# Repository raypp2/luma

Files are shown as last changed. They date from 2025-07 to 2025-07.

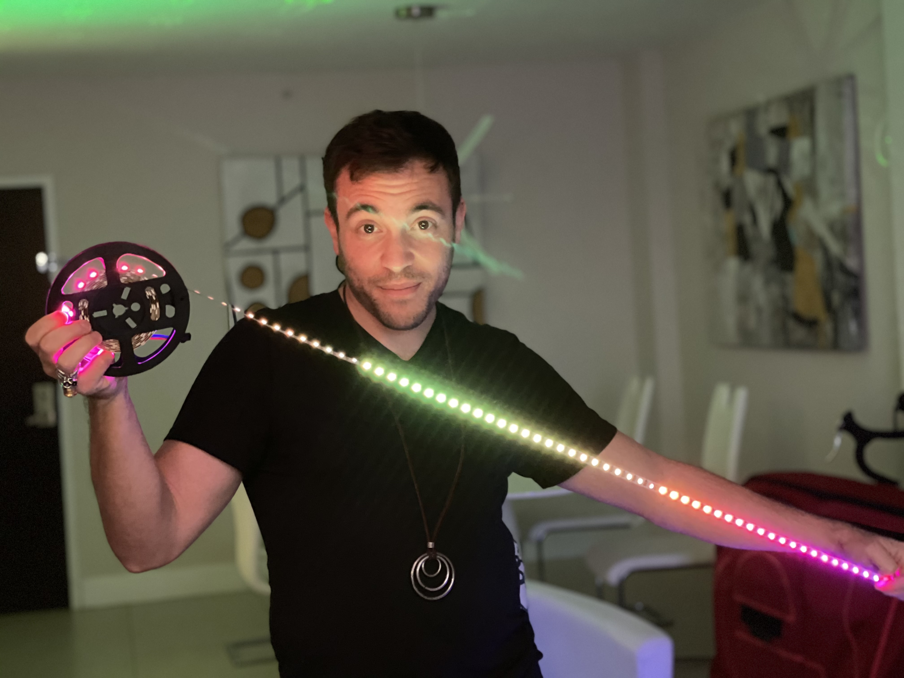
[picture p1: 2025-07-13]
microsite/teamPhotos/ray.jpg

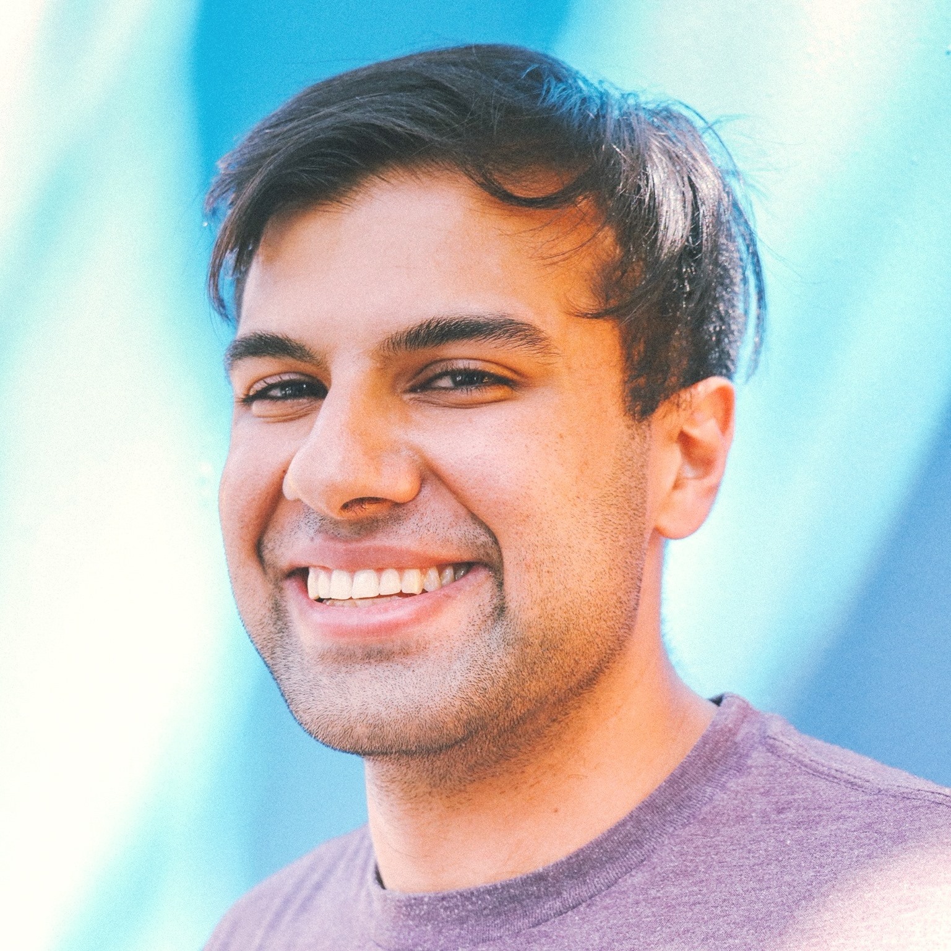
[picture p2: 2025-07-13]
microsite/teamPhotos/neil.jpg

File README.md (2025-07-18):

# Luma LED Pendant

<u>Overview</u> &nbsp;&nbsp;&nbsp;|&nbsp;&nbsp;&nbsp; [🧭 Laser Cutting](./documentation/laser.md) &nbsp;&nbsp;&nbsp;|&nbsp;&nbsp;&nbsp; [🛠️ 3D Printing](./documentation/3dmodel.md) &nbsp;&nbsp;&nbsp;|&nbsp;&nbsp;&nbsp; [🔮 Roadmap](./documentation/roadmap.md)

*This is a short description*

**Technical Notes**:
- Bullet 1
- Bullet 2

## 🙋‍♂️ Who is this for

Something about who this is for, what it does, and why it is useful.

## TODO

[] Apply google analytics
[] Write basic documentation on Github
[] Update team to instagram tags

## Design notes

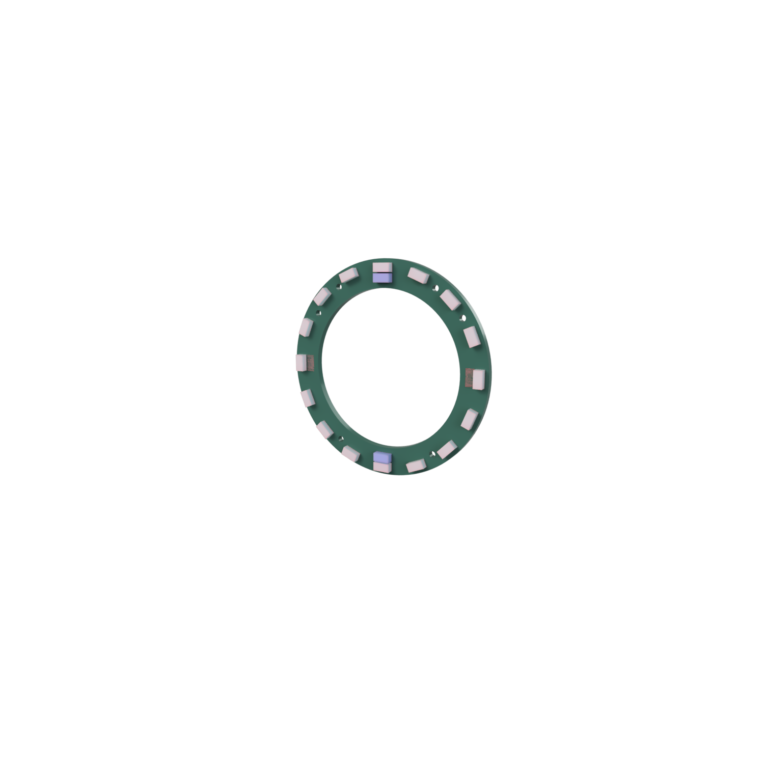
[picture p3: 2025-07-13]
moodBoardAssets/pcb.png

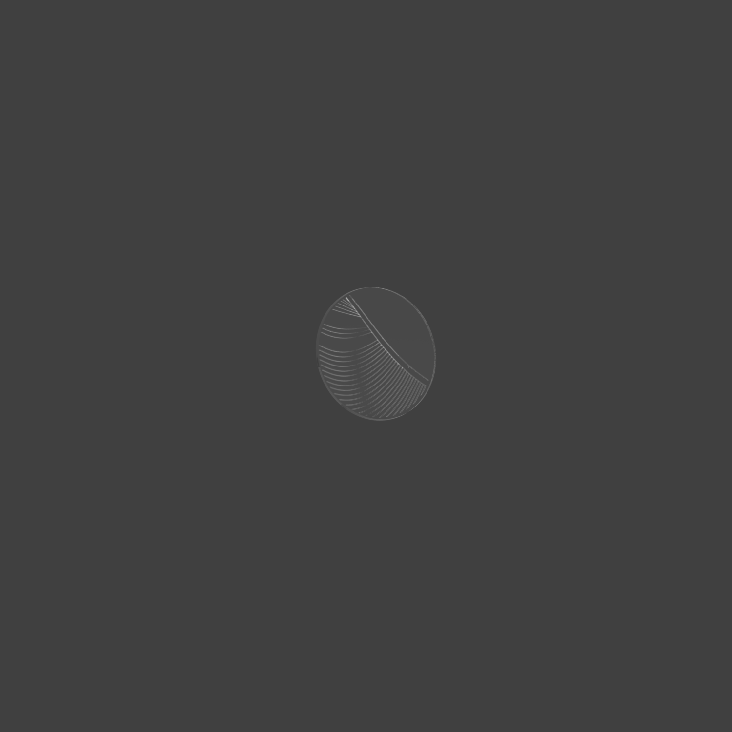
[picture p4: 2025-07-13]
moodBoardAssets/acrylic-back.png

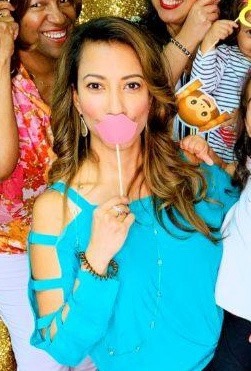
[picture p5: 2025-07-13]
microsite/teamPhotos/trisha.jpg

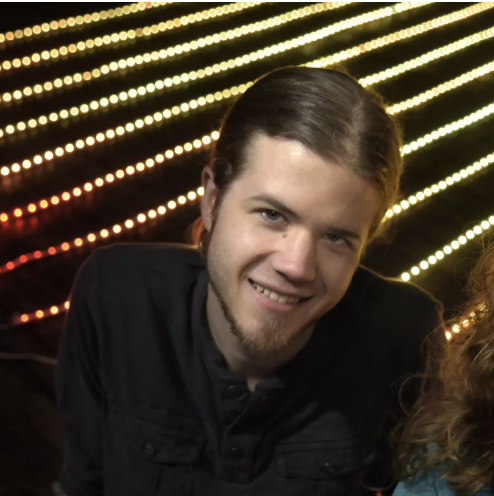
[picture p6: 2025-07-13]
microsite/teamPhotos/kyle.png

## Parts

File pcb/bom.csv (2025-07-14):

Comment | Designator | Footprint | LCSC Part Number
0.1uF | C1,C2,C3,C4,C5,C6,C7,C8,C9,C10,C11,C12,C13,C14,C15,C16,C17 | 0402 | C1525
SK6812SIDE-A-S Side edmit addressible LED | LED18,LED11,LED17,LED3,LED10,LED9,LED13,LED8,LED6,LED16,LED2,LED12,LED7,LED5,LED14,LED4,LED1,LED15,LED19,LED20 | SMD-4P,4x1.6mm | C5378737
TS-1187A-C-J-B 5.1mm momentary button 5mm plunger | SW1,SW2 | SMD | C318885
ATtiny1616-M | U1 | QFN-20-EP | C507118

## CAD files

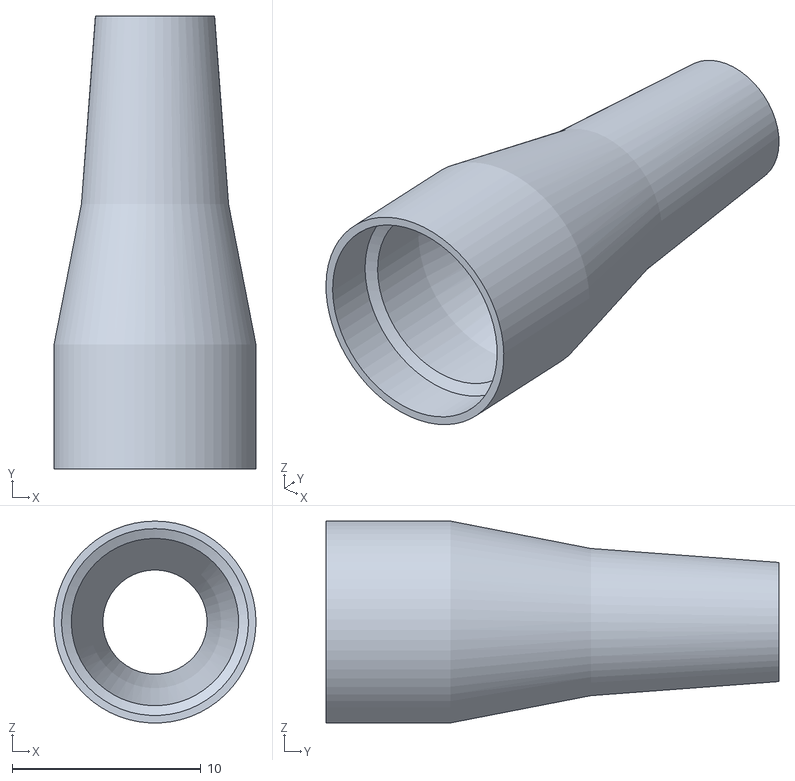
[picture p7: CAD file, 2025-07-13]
batteryEnclosure3D/Luma Pendant 3 Battery v7 wire sleeve.stl
10.7 x 24.0 x 10.7

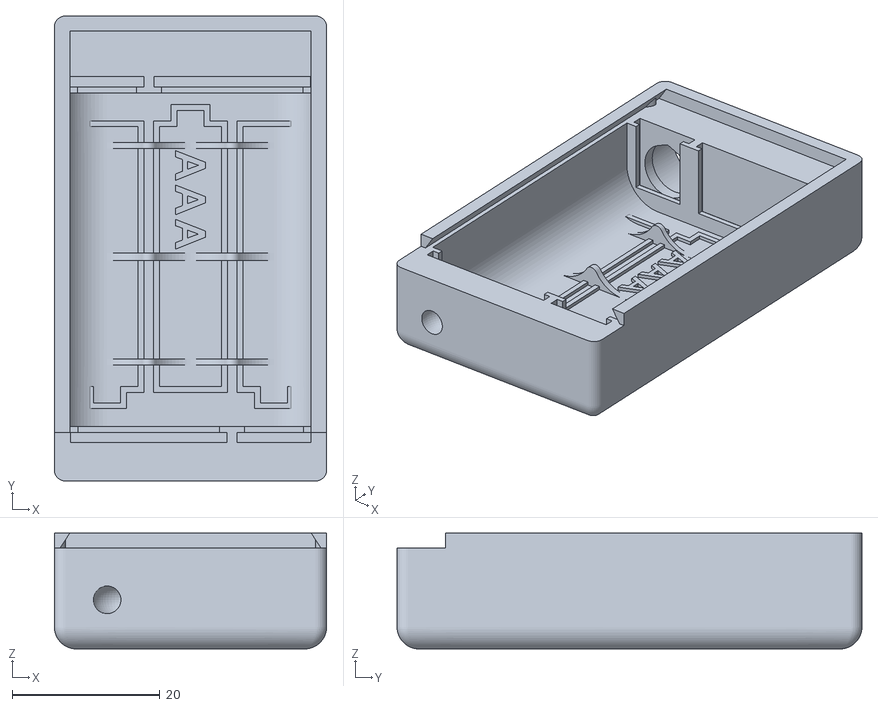
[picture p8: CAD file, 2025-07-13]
batteryEnclosure3D/Luma Pendant 3 Battery v7 case.stl
36.9 x 63.0 x 15.7

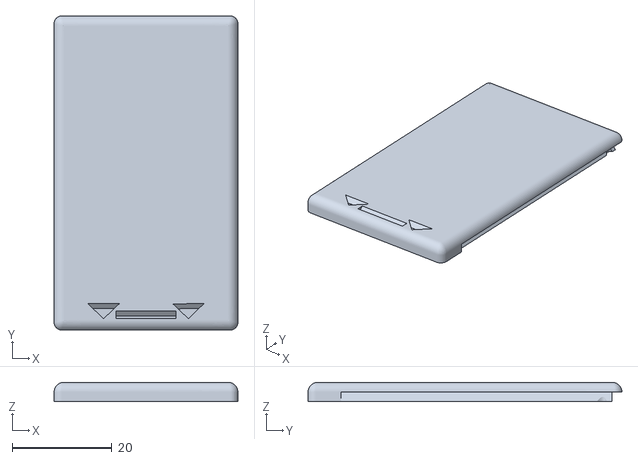
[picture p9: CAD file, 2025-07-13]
batteryEnclosure3D/Luma Pendant 3 Battery v7 Lid.stl
36.9 x 63.0 x 3.90

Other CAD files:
batteryEnclosure3D/Luma Pendant 3 Battery v7.f3d

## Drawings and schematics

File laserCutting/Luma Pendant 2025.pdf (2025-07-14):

## FRONT

# ART

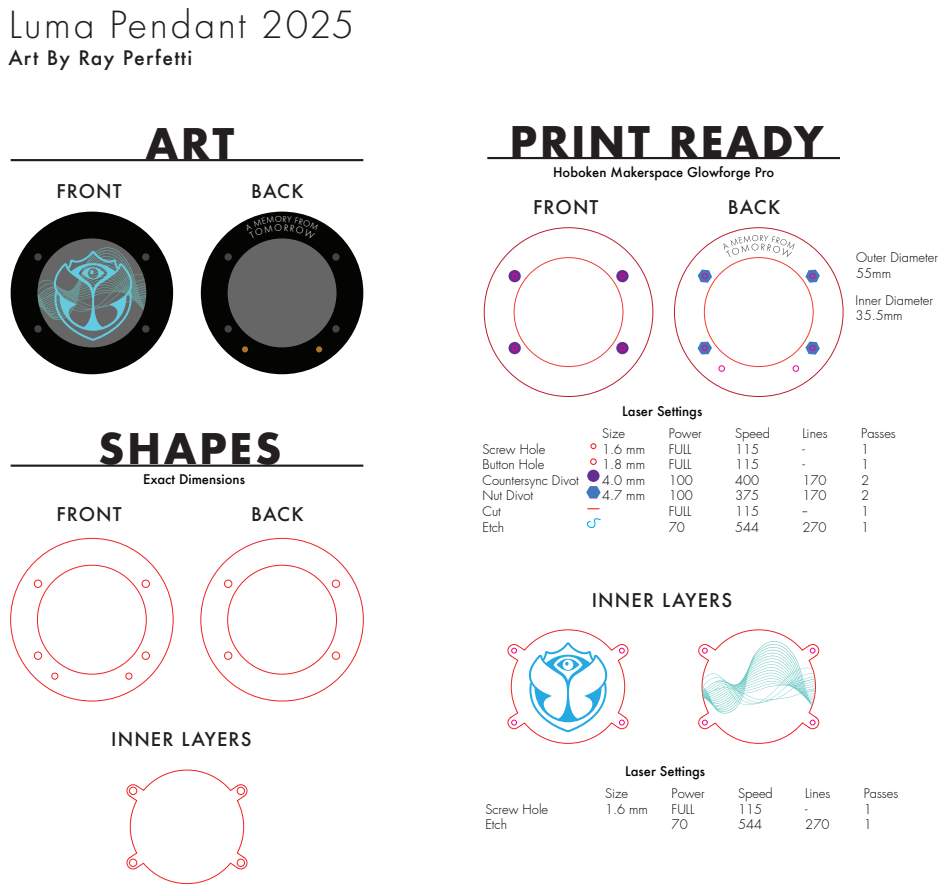
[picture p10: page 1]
BACK; Exact Dimensions; FRONT; INNER LAYERS; SHAPES; Laser Settings; Screw Hole Button Hole Countersync Divot Nut Divot Cut Etch; Size 1.6 mm 1.8 mm 4.0 mm 4.7 mm; Outer Diameter 55mm; Inner Diameter 35.5mm; Power FULL FULL 100 100 FULL 70; Speed 115 115 400 375 115 544; Lines - - 170 170 -- 270; Passes 1 1 2 2 1 1; Screw Hole Etch; Size 1.6 mm; Power FULL 70; Speed 115 544; Lines - 270; Passes 1 1; PRINT READY; A TOMOR ROW; MEMORY FROM

Luma Pendant 2025
Art By Ray Perfetti

Hoboken Makerspace Glowforge Pro
FRONT

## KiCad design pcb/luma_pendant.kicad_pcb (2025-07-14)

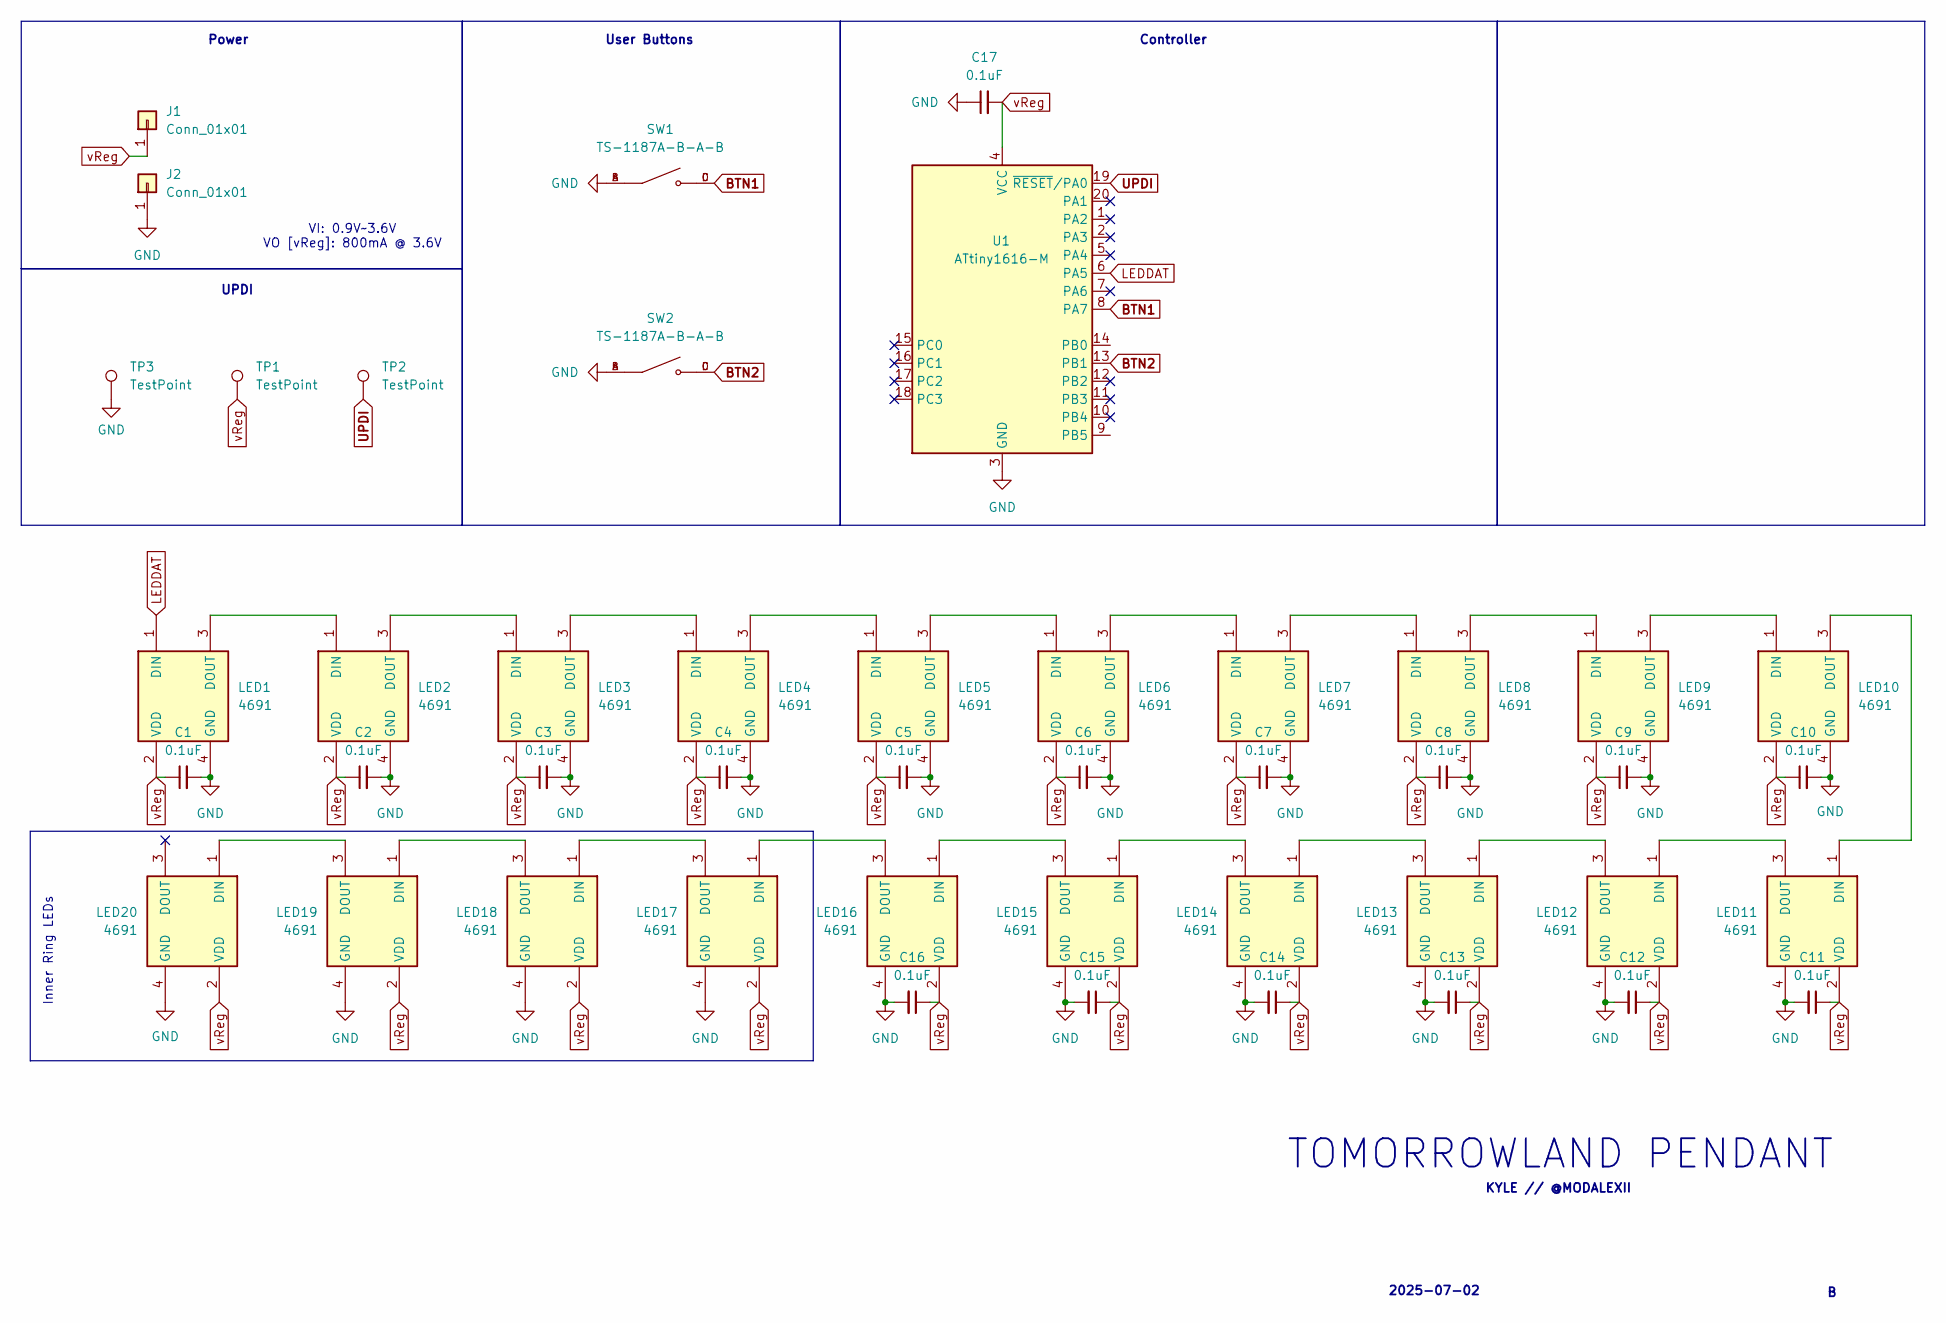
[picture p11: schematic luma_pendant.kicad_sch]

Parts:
C1, C2, C3, C4, C5, C6, C7, C8, C9, C10, C11, C12, C13, C14, C15, C16, C17: 0.1uF; C_0402_1005Metric
J1: Conn_01x01; TestPoint_THTPad_2.0x2.0mm_Drill1.0mm
J2: Conn_01x01; TestPoint_THTPad_D2.0mm_Drill1.0mm
LED1, LED2, LED3, LED4, LED5, LED6, LED7, LED8, LED9, LED10, LED11, LED12, LED13, LED14, LED15, LED16, LED17, LED18, LED19, LED20: 4691; Mouser Part Number 485-4691
SW1, SW2: TS-1187A-B-A-B; SW_TS-1187A-B-A-B; PARTREV A0
TP1, TP2, TP3: TestPoint; TestPoint_THTPad_D1.5mm_Drill0.7mm
U1: ATtiny1616-M; VQFN-20-1EP_3x3mm_P0.4mm_EP1.7x1.7mm

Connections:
BTN1: SW1.C, SW1.D, U1.8 (PA7)
BTN2: SW2.C, SW2.D, U1.13 (PB1)
GND: C1.2, C2.2, C3.2, C4.2, C5.2, C6.2, C7.2, C8.2, C9.2, C10.2, C11.2, C12.2, C13.2, C14.2, C15.2, C16.2, C17.1, J2.1, LED1.4 (GND), LED2.4 (GND), LED3.4 (GND), LED4.4 (GND), LED5.4 (GND), LED6.4 (GND), LED7.4 (GND), LED8.4 (GND), LED9.4 (GND), LED10.4 (GND), LED11.4 (GND), LED12.4 (GND), LED13.4 (GND), LED14.4 (GND), LED15.4 (GND), LED16.4 (GND), LED17.4 (GND), LED18.4 (GND), LED19.4 (GND), LED20.4 (GND), SW1.A, SW1.B, SW2.A, SW2.B, TP3.1, U1.3 (GND), U1.21 (GND)
LEDDAT: LED1.1 (DIN), U1.6 (PA5)
unnamed: LED1.3 (DOUT), LED2.1 (DIN)
unnamed: LED2.3 (DOUT), LED3.1 (DIN)
unnamed: LED3.3 (DOUT), LED4.1 (DIN)
unnamed: LED4.3 (DOUT), LED5.1 (DIN)
unnamed: LED5.3 (DOUT), LED6.1 (DIN)
unnamed: LED6.3 (DOUT), LED7.1 (DIN)
unnamed: LED7.3 (DOUT), LED8.1 (DIN)
unnamed: LED8.3 (DOUT), LED9.1 (DIN)
unnamed: LED9.3 (DOUT), LED10.1 (DIN)
unnamed: LED10.3 (DOUT), LED11.1 (DIN)
unnamed: LED11.3 (DOUT), LED12.1 (DIN)
unnamed: LED12.3 (DOUT), LED13.1 (DIN)
unnamed: LED13.3 (DOUT), LED14.1 (DIN)
unnamed: LED14.3 (DOUT), LED15.1 (DIN)
unnamed: LED15.3 (DOUT), LED16.1 (DIN)
unnamed: LED16.3 (DOUT), LED17.1 (DIN)
unnamed: LED17.3 (DOUT), LED18.1 (DIN)
unnamed: LED18.3 (DOUT), LED19.1 (DIN)
unnamed: LED19.3 (DOUT), LED20.1 (DIN)
UPDI: TP2.1, U1.19 (~RESET/PA0)
vReg: C1.1, C2.1, C3.1, C4.1, C5.1, C6.1, C7.1, C8.1, C9.1, C10.1, C11.1, C12.1, C13.1, C14.1, C15.1, C16.1, C17.2, J1.1, LED1.2 (VDD), LED2.2 (VDD), LED3.2 (VDD), LED4.2 (VDD), LED5.2 (VDD), LED6.2 (VDD), LED7.2 (VDD), LED8.2 (VDD), LED9.2 (VDD), LED10.2 (VDD), LED11.2 (VDD), LED12.2 (VDD), LED13.2 (VDD), LED14.2 (VDD), LED15.2 (VDD), LED16.2 (VDD), LED17.2 (VDD), LED18.2 (VDD), LED19.2 (VDD), LED20.2 (VDD), TP1.1, U1.4 (VCC)

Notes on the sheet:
2025-07-02
VI: 0.9V~3.6V VO [vReg]: 800mA @ 3.6V
Controller
Inner Ring LEDs
KYLE // @MODALEXII
Power
TOMORROWLAND PENDANT
UPDI
User Buttons

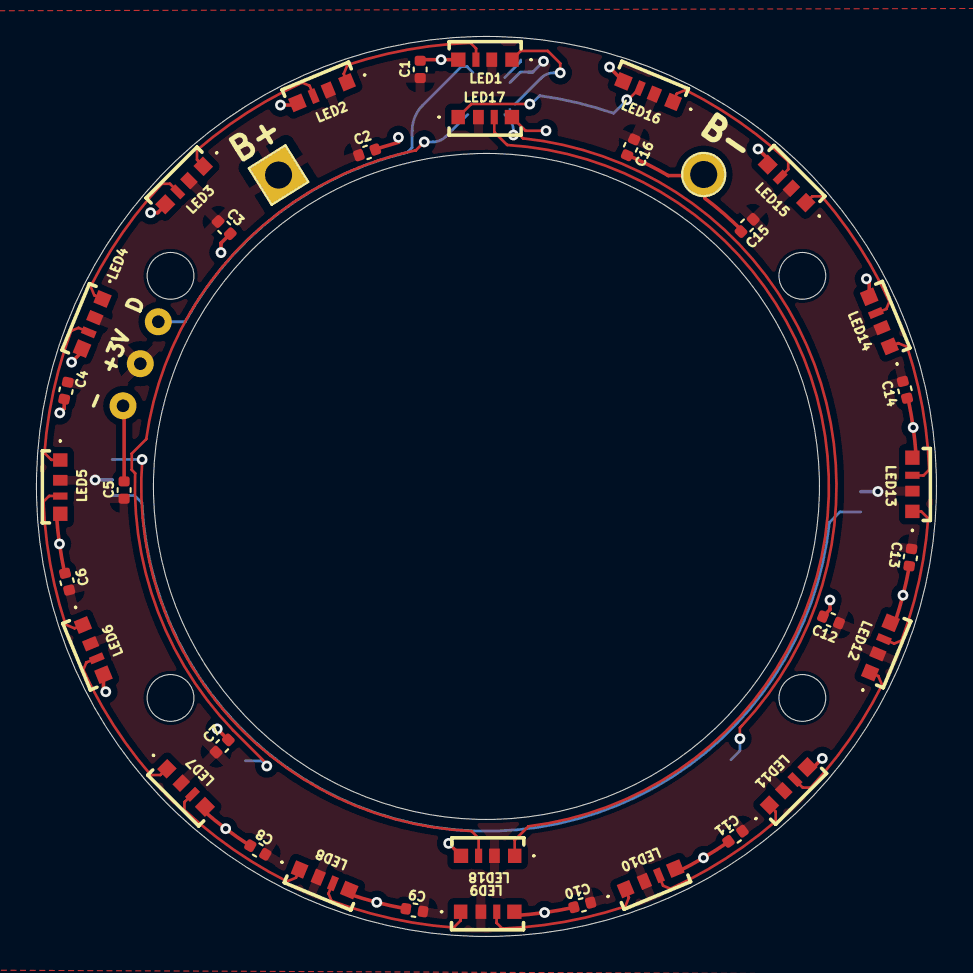
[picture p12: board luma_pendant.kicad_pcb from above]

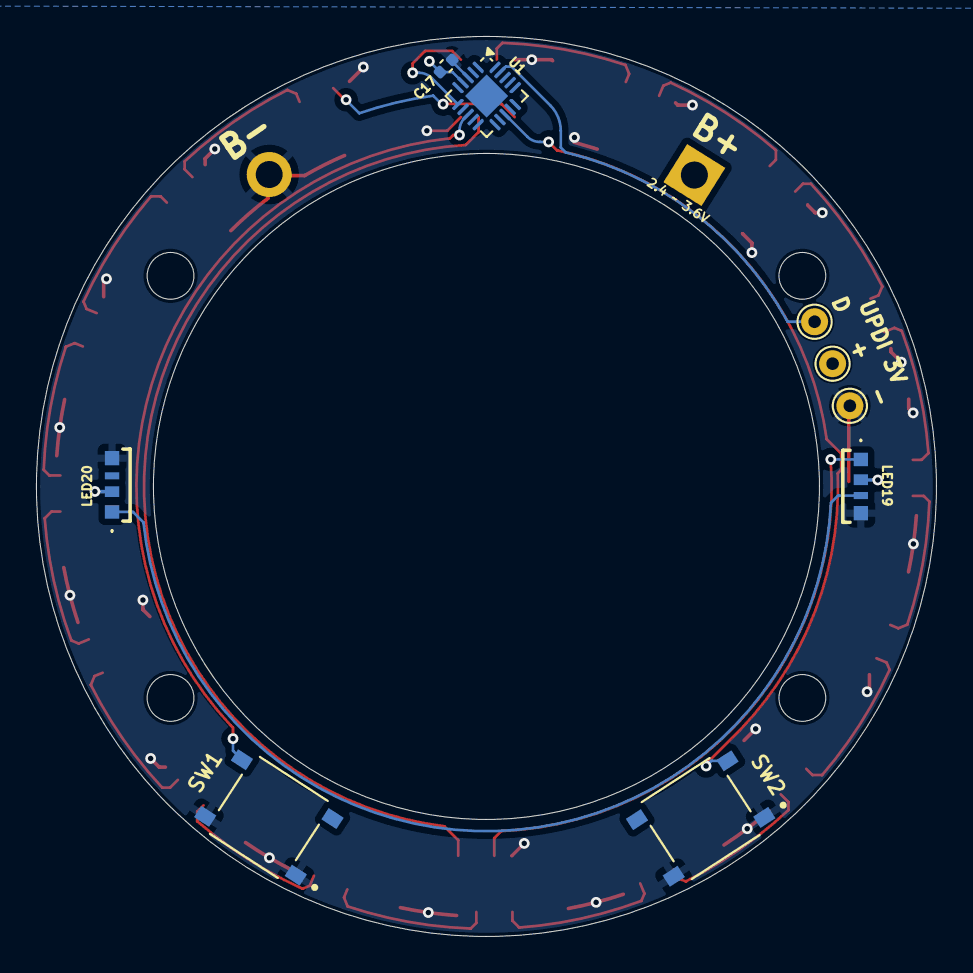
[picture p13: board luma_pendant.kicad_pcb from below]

Board: 2 copper layers, 50.0 x 50.0 mm, 45 parts (9 on the bottom side), 25 nets.

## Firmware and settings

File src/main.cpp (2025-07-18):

/*

 MegaTinyCore => ATtiny1616 @ 16MHz (internal)

*/

#include <Arduino.h>
#include <Bounce2.h> 
#include <FastLED.h> // re: below, see https://github.com/FastLED/FastLED/issues/1754
#include <EEPROM.h>

// Hardware specific macros
#define BTN_1_PIN 3 // megaTinyCore # for PA7
#define BTN_2_PIN 8 // megaTinyCore # for PB1
#define DATA_PIN 1 // megaTinyCore # for PA5
#define NUM_LEDS 20
#define ANIMATION_FPS 129 // This is the typical BPM of EDM music
#define EEPROM_ADDR_OUTER 0
#define EEPROM_ADDR_INNER 1
#define EEPROM_ADDR_BRIGHTNESS 2
#define ARRAY_SIZE(A) (sizeof(A) / sizeof((A)[0]))

// Global brightness macros
#define BRIGHTNESS_CYCLE_LEN 4

// LED Segments - Use to simplify control of outer/acrylic front/back
CRGB leds_raw[NUM_LEDS];
CRGBSet leds(leds_raw, NUM_LEDS);
CRGBSet leds_outer(leds(0, 15)); 
CRGBSet leds_inner_front(leds(16, 17)); 
CRGBSet leds_inner_back(leds(18, 19));

// Pattern specific global variables
Bounce button_1 = Bounce(); 
Bounce button_2 = Bounce();

uint8_t outerCurrentPattern = 0; // Index number of which pattern is current
uint8_t innerCurrentPattern = 0; // Index number of which pattern is current
uint8_t outerHuePosition = 0;    // Rotating "base color" used by many of the patterns
uint8_t innerHuePosition = 0;    // Rotating "base color" used by many of the patterns
int outerLEDPosition = 0;        // Marker for point-based animations

// Patter brightness specific global variables
uint8_t brightnessLevelIndex = 0;     // Used to iterate through the button 2 brightness level presses

const uint8_t BRIGHTNESS_LEVELS_OUTER[BRIGHTNESS_CYCLE_LEN] = {20, 50, 100, 0};
const uint8_t BRIGHTNESS_LEVELS_OUTER_PULSE_HEAD[BRIGHTNESS_CYCLE_LEN] = {25, 75, 150, 0};
const uint8_t BRIGHTNESS_LEVELS_INNER_FRONT[BRIGHTNESS_CYCLE_LEN] = {10, 60, 125, 125};
const uint8_t BRIGHTNESS_LEVELS_INNER_BACK[BRIGHTNESS_CYCLE_LEN] = {10, 60, 125, 125};

uint8_t BRIGHTNESS_OUTER = BRIGHTNESS_LEVELS_OUTER[0];                       // Sets the "Low" brightness level for the outer leds
uint8_t BRIGHTNESS_OUTER_PULSE_HEAD = BRIGHTNESS_LEVELS_OUTER_PULSE_HEAD[0]; // Sets the "Low" brightness level for the pulse heads 
uint8_t BRIGHTNESS_INNER_FRONT = BRIGHTNESS_LEVELS_INNER_FRONT[0];           // Sets the "Low" brightness level for the inner front leds
uint8_t BRIGHTNESS_INNER_BACK = BRIGHTNESS_LEVELS_INNER_BACK[0];             // Sets the "Low" brightness level for the inner back leds




// Need to forward declarations for the patterns here -- update with new patterns
// Outer patterns
void wispyRainbow();
void berlinMode();
void cyanMode();
void magentaMode();
void wmTiamat();
void sinelonDualEffect();
void bpm();
void bpmFlood();
void outerCycle();

// Inner patterns
void innerCycle();
void innerCrossfadePalette();
void innerCrossfadeRedWhite();
void innerCrossfadeOrangeCyan();
void innerCrossfadeMagentaTurquoise();
void innerEDMSoundReactive_Rainbow();
void innerEDMSoundReactive_Cyan();
void innerEDMSoundReactive_Magenta();
void innerComplementaryCycle();

// Helper functions
void dualSinePulsePattern(uint8_t red, uint8_t green, uint8_t blue);
void washingMachineEffect(CRGBPalette16 palette);

/*
 * List of patterns to cycle through on button press.  Each is defined as a separate function below.
 * The outer patterns and the inner patters will be 1-to-1.
 */

typedef void (*PatternList[])();

PatternList outerPatternList = {
  outerCycle,
  wispyRainbow,
  berlinMode, 
  cyanMode, 
  magentaMode, 
  wmTiamat, 
  sinelonDualEffect, 
  bpm, 
  bpmFlood
}; 

PatternList innerPatternList = { 
  innerCycle,                     // outerCycle
  innerComplementaryCycle,        // wispyRainbow
  innerCrossfadeRedWhite,         // berlin mode
  innerCrossfadeOrangeCyan,       // cyanMode
  innerCrossfadeMagentaTurquoise, // magentaMode
  innerCrossfadePalette,          // wmTiamat
  innerCrossfadePalette,          // sinelonDualEffect
  innerEDMSoundReactive_Rainbow,  // bpm
  innerCrossfadePalette,  // bpmFlood
}; 

/* 
 ---  Custom Palette Definitions ---
*/

// rainbow for various patterns, heavily tweaked to look ok on the tomorrowland pendant outer ring
DEFINE_GRADIENT_PALETTE(rainbowLoopAgroGamma) {
      0, 255,   0,   0,   // Red 
     21, 255,  60,   0,   // Red-Orange 
     42, 220, 128,   0,   // Yellow 
     63,  80, 255,   0,   // Yellow-Green 
     85,   0, 255,   0,   // Green 
    106,   0, 255, 128,   // Green-Cyan
    127,   0, 220, 255,   // Cyan 
    148,   0,  80, 255,   // Cyan-Blue
    169,   0,   0, 255,   // Blue 
    190,  20,   0, 255,   // Blue-Violet
    211, 128,   0, 120,   // Magenta 
    232, 255,   0,  20,   // Magenta-Red
    255, 255,   0,   0    // Red (back to zero)
};

CRGBPalette16 myRainbowPalette = rainbowLoopAgroGamma;

// Tiamat palette adapted from WLED
// A bright meteor with blue, teal and magenta hues
DEFINE_GRADIENT_PALETTE(tiamatAgroGamma) {
    0,   1,  2, 14,   // Very dark navy (nearly black-blue)
   33,   2,  5, 35,   // Midnight blue
  100,  13,135, 92,   // Teal green (deep jade)
  120,  43,255,193,   // Bright aqua mint
  140, 247,  7,249,   // Neon pink-violet
  160, 193, 17,208,   // Electric purple
  180,  39,255,154,   // Bright seafoam green
  200,   4,213,236,   // Electric cyan (vivid)
  220,  39,252,135,   // Bright spring green
  240, 193,213,253,   // Light periwinkle / icy blue
  255, 255,249,255    // Near white with pink tint (pastel)
};

CRGBPalette16 tiamatPalette = tiamatAgroGamma;

// Yelmag-inspired palette (warm yellows with magenta and red)
DEFINE_GRADIENT_PALETTE(yelmagAgroGamma) {
    0,   0,   0,   0, // Black
   42, 113,   0,   0, // Dark Red / Maroon
   84, 255,   0,   0, // Pure Red
  127, 255,   0, 117, // Hot Pink / Red-Magenta mix
  170, 255,   0, 255, // Magenta
  212, 255, 128, 117, // Light Red-Orange / Coral
  255, 255, 255,   0  // Yellow
};

CRGBPalette16 yelmagPalette = yelmagAgroGamma;

// Sherbet palette from WLED (soft pinks, oranges, and whites)
DEFINE_GRADIENT_PALETTE(rainbowSherbetAgroGamma) {
    0,   255, 102,  41,   // dark orange
   43,   255, 140,  90,   // peach
   86,   255,  51,  90,   // hot pink
  127,   255, 153, 169,   // soft pink
  170,   255, 255, 249,   // off-white
  209,   113, 255,  85,   // green-lime
  255,   157, 255, 137    // mint-lime
};

CRGBPalette16 sherbetPalette = rainbowSherbetAgroGamma;

void setup() {
  FastLED.addLeds<WS2812,DATA_PIN,GRB>(leds, NUM_LEDS);

  pinMode(BTN_1_PIN,INPUT_PULLUP);
  button_1.attach(BTN_1_PIN);
  button_1.interval(100); // interval in ms
  
  pinMode(BTN_2_PIN,INPUT_PULLUP);
  button_2.attach(BTN_2_PIN);
  button_2.interval(100); // interval in ms

  // Read saved pattern indices
  outerCurrentPattern = EEPROM.read(EEPROM_ADDR_OUTER);
  innerCurrentPattern = EEPROM.read(EEPROM_ADDR_INNER);
  brightnessLevelIndex = EEPROM.read(EEPROM_ADDR_BRIGHTNESS);

  // Safety bounds check
  if (outerCurrentPattern >= ARRAY_SIZE(outerPatternList)) outerCurrentPattern = 0;
  if (innerCurrentPattern >= ARRAY_SIZE(innerPatternList)) innerCurrentPattern = 0;

  BRIGHTNESS_OUTER = BRIGHTNESS_LEVELS_OUTER[brightnessLevelIndex];
  BRIGHTNESS_OUTER_PULSE_HEAD = BRIGHTNESS_LEVELS_OUTER_PULSE_HEAD[brightnessLevelIndex];
  BRIGHTNESS_INNER_FRONT = BRIGHTNESS_LEVELS_INNER_FRONT[brightnessLevelIndex];
  BRIGHTNESS_INNER_BACK = BRIGHTNESS_LEVELS_INNER_BACK[brightnessLevelIndex];
}

// This is not used here - but we need to add it in order to support FastLED requirements
volatile unsigned long timer_millis = 0;
void update_millis() {
    static unsigned long last_micros = 0;
    unsigned long current_micros = micros();
    if (current_micros - last_micros >= 1000) {
        timer_millis++;
        last_micros = current_micros;
    }
}

// native SetBrightness() does not accept a CRGBSet
void setSegBrightness(CRGBSet& segment, uint8_t brightness) {
  for (uint16_t i = 0; i < segment.len; i++) {
    segment[i].r = scale8(segment[i].r, brightness);
    segment[i].g = scale8(segment[i].g, brightness);
    segment[i].b = scale8(segment[i].b, brightness);
  }
}

/* 
 --- Outer LED Patterns ---
*/

#define PULSE_DECAY 0.85f // Fade by % each step

void dualSinePulsePattern(uint8_t red, uint8_t green, uint8_t blue) {
  // This is a master timer that moves the waves. The number controls the speed.
  uint8_t master_phase = beat8(15);

  for (int i = 0; i < leds_outer.len; i++) {
    // Map the LED's physical position to a point on a circle (0-255).
    uint8_t led_angle = map(i, 0, leds_outer.len, 0, 255);

    // Calculate the brightness from the two opposing waves.
    uint8_t brightness1 = sin8(led_angle + master_phase);
    uint8_t brightness2 = sin8(led_angle + master_phase + 128);

    // Take the brighter of the two waves as our base.
    uint8_t raw_brightness = max(brightness1, brightness2);

    // Extra contrast boost and smooth easing.
    uint8_t contrast_brightness = scale8(raw_brightness, raw_brightness);
    contrast_brightness = scale8(contrast_brightness, contrast_brightness); // extra contrast
    uint8_t eased_brightness = ease8InOutCubic(contrast_brightness);

    // Apply the specified color, scaled by our adjusted brightness.
    leds_outer[i] = CRGB(red, green, blue);
    leds_outer[i].nscale8(scale8(eased_brightness, BRIGHTNESS_OUTER));
  }
}


// Wispy Dynamic Rainbow Spin Pattern
void wispyRainbow() {
  const uint8_t WISPY_BRIGHTNESS_SCALING = 150;
  // set outer_led to have a rainbow pattern
  //fill_rainbow(leds_outer, leds_outer.len, 0, 360/leds_outer.len, 240, 100);
  for (int i = 0; i < leds_outer.len; i++) {
    uint8_t colorIndex = (outerHuePosition + (i * (256 / leds_outer.len))) % 256;
    leds_outer[i] = ColorFromPalette(myRainbowPalette, colorIndex, 110, LINEARBLEND);
  }
  setSegBrightness(leds_outer, scale8(BRIGHTNESS_OUTER, WISPY_BRIGHTNESS_SCALING));
  EVERY_N_MILLISECONDS( 20 ) { outerHuePosition++; }

  // set the head
  leds_outer[outerLEDPosition] = leds_outer[outerLEDPosition].nscale8_video(BRIGHTNESS_OUTER_PULSE_HEAD);

  // set the opposing head
  int oppositePos = (outerLEDPosition + leds_outer.len / 2) % leds_outer.len;
  leds_outer[oppositePos] = leds_outer[oppositePos].nscale8_video(BRIGHTNESS_OUTER_PULSE_HEAD);

   // move the head with dynamic movement speed using a sine wave
  static uint16_t lastMoveTime = 0;
  uint16_t now = millis();

  // Speed oscillates between 30ms and 150ms per move at ~0.25Hz (i.e., ~4s full cycle)
  uint16_t dynamicSpeed = beatsin16(15, 30, 150); 

  if (now - lastMoveTime > dynamicSpeed) {
    outerLEDPosition = (outerLEDPosition + 1) % leds_outer.len;
    lastMoveTime = now;
  }

  // dim the tail
  EVERY_N_MILLISECONDS(50) {
    for (int i = 0; i < leds_outer.len; i++) {
      leds_outer[i].r = (uint8_t)(leds_outer[i].r * PULSE_DECAY);
      leds_outer[i].g = (uint8_t)(leds_outer[i].g * PULSE_DECAY);
      leds_outer[i].b = (uint8_t)(leds_outer[i].b * PULSE_DECAY);
    }
  }
}

void berlinMode() {
  const uint8_t BERLIN_BRIGHTNESS_SCALING = 200;  // Adjust this value (0–255)
  uint8_t scaledBrightness = scale8(BRIGHTNESS_OUTER, BERLIN_BRIGHTNESS_SCALING);
  dualSinePulsePattern(scaledBrightness, 0, 0);
}

void cyanMode() {
  dualSinePulsePattern(0, BRIGHTNESS_OUTER, BRIGHTNESS_OUTER);
}

void magentaMode() {
  dualSinePulsePattern(BRIGHTNESS_OUTER, 0, BRIGHTNESS_OUTER);
}

// Imitates a washing machine, rotating same waves forward,
// then pause, then backwards.
// Adapted from WLED: https://github.com/wled/WLED/blob/main/wled00/FX.cpp#L4478
void washingMachineEffect(CRGBPalette16 palette) {
  static uint8_t wmSpeed = 8;                     // Lower is slower
  uint8_t wmIntensity = BRIGHTNESS_OUTER;  // Brightness peak (0–255)
  static CRGBPalette16 wmPalette = palette;

  // Position moves back and forth like a washer drum oscillating
  uint16_t pos = beatsin16(wmSpeed, 0, leds_outer.len - 1);
  // Brightness pulsing
  uint8_t bri = beatsin8(wmSpeed * 2, wmIntensity / 4, wmIntensity);

  // Fade existing frame for trailing effect
  fadeToBlackBy(leds_outer, leds_outer.len, 20);

  // Main color from palette
  CRGB c = ColorFromPalette(wmPalette, (uint8_t)(pos * (255 / leds_outer.len)), bri);

  // Light up the head
  leds_outer[pos] = c;

  // Light up the opposing head (180 degrees apart)
  uint16_t pos2 = (pos + leds_outer.len / 2) % leds_outer.len;
  leds_outer[pos2] = c;
}

void wmTiamat() {
  washingMachineEffect(tiamatPalette);
}


// Dual Sinelon effect for leds_outer
void sinelonDualEffect() {
  // Static state variables
  static uint8_t beatA = 10;        // speed of first comet
  static uint8_t beatB = 7;         // speed of second comet
  static uint8_t indexA = 0;        // Color index A
  static uint8_t indexB = 127;      // Color index B

  // Fade existing frame by a small amount for trails
  fadeToBlackBy(leds_outer, leds_outer.len, 20);

  // Calculate positions using sinewave / ping-pong motion
  uint16_t posA = beatsin16(beatA, 0, leds_outer.len - 1);
  uint16_t posB = beatsin16(beatB, 0, leds_outer.len - 1);

  // Colors from Sherbet palette
  for (int i = 0; i < leds_outer.len; i++) {
    uint8_t colorIndexA = (indexA + (i * (256 / leds_outer.len))) % 256;
    uint8_t colorIndexB = (indexB + (i * (256 / leds_outer.len))) % 256;
    leds_outer[posA] = ColorFromPalette(sherbetPalette, colorIndexA, 110, LINEARBLEND);
    leds_outer[posB] = ColorFromPalette(sherbetPalette, colorIndexB, 110, LINEARBLEND);
  }
  leds_outer[posA].nscale8(BRIGHTNESS_OUTER);
  leds_outer[posB].nscale8(BRIGHTNESS_OUTER);

  // Advance palette indices slowly
  EVERY_N_MILLISECONDS(20) {
    indexA += 1;
    indexB += 1;
  }
}

// colored stripes pulsing at a defined Beats-Per-Minute (BPM)
void bpm() {
  const uint8_t BPM_BRIGHTNESS_SCALING = 150;
  uint8_t BeatsPerMinute = 32;
  uint8_t beat = beatsin8(BeatsPerMinute, 64, 255);
  for (int i = 0; i < leds_outer.len; i++) {
    uint8_t colorIndex = (outerHuePosition + (i * (256 / leds_outer.len))) % 256;
    leds_outer[i] = ColorFromPalette(myRainbowPalette, colorIndex, beat-1+(i*10), LINEARBLEND);
    leds_outer[i].nscale8(scale8(BRIGHTNESS_OUTER, BPM_BRIGHTNESS_SCALING));
  }
}

// All outer leds pulsing at a defined Beats-Per-Minute (BPM)
void bpmFlood() {
  const uint8_t BPM_BRIGHTNESS_SCALING = 150;
  uint8_t BeatsPerMinute = 32;
  uint8_t beat = beatsin8(BeatsPerMinute, 32, 128);
  CRGB color = ColorFromPalette(myRainbowPalette, beat, 110);
  fill_solid(leds_outer, leds_outer.len, color);
  setSegBrightness(leds_outer, scale8(BRIGHTNESS_OUTER, BPM_BRIGHTNESS_SCALING));
}

void outerCycle() {
  void (**outerPatternListCycle)() = outerPatternList;
  static uint8_t current = 2; // Start at index 2 to avoid first two patterns
  static unsigned long lastChangeTime = 0;
  static bool firstRun = true;

  // Call the current pattern
  outerPatternListCycle[current]();

  // Every 10 seconds, advance to the next pattern, or on first run
  unsigned long now = millis();
  if (now - lastChangeTime >= 10000 || firstRun) {
    lastChangeTime = now;
    current++;
    if (current >= ARRAY_SIZE(outerPatternList)) current = 1;
    FastLED.clear();  // Optional: wipe leftover LEDs when switching
    firstRun = false;
  }
}

/* 
 --- Inner LED Patterns ---
*/

void innerCrossfadePalette() {
  // --- Static variables to hold state ---
  static uint8_t back_palette_index = 0;
  static uint8_t front_palette_index = 1; // Start one step ahead for color separation
  static bool back_is_active = false;
  static bool front_is_active = false;

  const uint8_t INNER_CROSSFADE_BRIGHTNESS_SCALING = 150;

  // --- TIMING & CONFIGURATION ---
  const uint8_t BPM = 15;
  const uint8_t LED1_DURATION = 100;
  const uint8_t LED2_DURATION = 100;
  const uint8_t PALETTE_STEP = 50;
  const uint8_t TOTAL_CYCLE_DURATION = 160;
  // This offset shifts the front panel's animation in time.
  // An offset of half the cycle duration makes it perfectly opposite.
  const uint8_t FRONT_PANEL_OFFSET = 60; //TOTAL_CYCLE_DURATION / 2; // e.g., 80

  // --- Master Beat Timers ---
  uint8_t back_beat = map(beat8(BPM), 0, 255, 0, TOTAL_CYCLE_DURATION);
  // The front panel's timer is the same, just offset.
  uint8_t front_beat = (back_beat + FRONT_PANEL_OFFSET) % TOTAL_CYCLE_DURATION;


  // --- Helper function to calculate animation for a single panel ---
  // This avoids code duplication and keeps the logic clean.
  auto calculatePanelAnimation = [](uint8_t beat, uint8_t duration1, uint8_t duration2, CRGB& color1, CRGB& color2, uint8_t& brightness1, uint8_t& brightness2) {
    // Determine the start times based on the duration. This is just for calculation.
    const uint8_t start1 = 0;
    const uint8_t start2 = (duration1 / 2) - (duration1 / 4); // Overlap logic

    if ((beat >= start1) && (beat < (start1 + duration1))) {
        uint8_t progress = beat - start1;
        uint8_t wave = triwave8(map(progress, 0, duration1 - 1, 0, 255));
        brightness1 = ease8InOutCubic(wave);
    }
    if ((beat >= start2) && (beat < (start2 + duration2))) {
        uint8_t progress = beat - start2;
        uint8_t wave = triwave8(map(progress, 0, duration2 - 1, 0, 255));
        brightness2 = ease8InOutCubic(wave);
    }
  };

  // --- Color Assignment ---
  // Check if the BACK panel's animation is starting a new cycle
  if (back_beat < 2 && !back_is_active) { // Use a small window to catch the start
    back_is_active = true;
    back_palette_index += (PALETTE_STEP * 2);
  } else if (back_beat > 2) {
    back_is_active = false;
  }
  // Check if the FRONT panel's animation is starting a new cycle
  if (front_beat < 2 && !front_is_active) {
    front_is_active = true;
    front_palette_index += (PALETTE_STEP * 2);
  } else if (front_beat > 2) {
    front_is_active = false;
  }

  // --- Brightness Calculation ---
  CRGB back_color1 = ColorFromPalette(myRainbowPalette, back_palette_index, 255, LINEARBLEND);
  CRGB back_color2 = ColorFromPalette(myRainbowPalette, back_palette_index + PALETTE_STEP, 255, LINEARBLEND);
  uint8_t b_bright1 = 0, b_bright2 = 0;
  calculatePanelAnimation(back_beat, LED1_DURATION, LED2_DURATION, back_color1, back_color2, b_bright1, b_bright2);

  CRGB front_color1 = ColorFromPalette(myRainbowPalette, front_palette_index, 255, LINEARBLEND);
  CRGB front_color2 = ColorFromPalette(myRainbowPalette, front_palette_index + PALETTE_STEP, 255, LINEARBLEND);
  uint8_t f_bright1 = 0, f_bright2 = 0;
  calculatePanelAnimation(front_beat, LED1_DURATION, LED2_DURATION, front_color1, front_color2, f_bright1, f_bright2);


  // --- Apply final values ---
  leds_inner_back[0] = back_color1;
  leds_inner_back[0].nscale8(scale8(scale8(b_bright1, BRIGHTNESS_INNER_BACK), INNER_CROSSFADE_BRIGHTNESS_SCALING));
  leds_inner_back[1] = back_color2;
  leds_inner_back[1].nscale8(scale8(scale8(b_bright2, BRIGHTNESS_INNER_BACK), INNER_CROSSFADE_BRIGHTNESS_SCALING));

  leds_inner_front[0] = front_color1;
  leds_inner_front[0].nscale8(scale8(scale8(f_bright1, BRIGHTNESS_INNER_FRONT), INNER_CROSSFADE_BRIGHTNESS_SCALING));
  leds_inner_front[1] = front_color2;
  leds_inner_front[1].nscale8(scale8(scale8(f_bright2, BRIGHTNESS_INNER_FRONT), INNER_CROSSFADE_BRIGHTNESS_SCALING));
}

void innerCrossfadeTwoColorCore(CRGB back_color, CRGB front_color) {
  // --- TIMING & CONFIGURATION ---
  const uint8_t BPM = 15;
  const uint8_t LED1_DURATION = 75;
  const uint8_t LED2_DURATION = 75;
  const uint8_t TOTAL_CYCLE_DURATION = 120;
  const uint8_t FRONT_PANEL_OFFSET = 40; //TOTAL_CYCLE_DURATION / 2; // 80

  // --- Master Beat Timers ---
  uint8_t back_beat = map(beat8(BPM), 0, 255, 0, TOTAL_CYCLE_DURATION);
  uint8_t front_beat = (back_beat + FRONT_PANEL_OFFSET) % TOTAL_CYCLE_DURATION;

  // --- Brightness variables (default to off) ---
  uint8_t back_brightness1 = 0, back_brightness2 = 0;
  uint8_t front_brightness1 = 0, front_brightness2 = 0;

  // --- Helper function to calculate brightness for a single panel ---
  auto calculatePanelBrightness = [](uint8_t beat, uint8_t duration1, uint8_t duration2, uint8_t& brightness1, uint8_t& brightness2) {
    // These start times are relative to the panel's own beat (0)
    const uint8_t start1 = 0;
    // This calculation creates the overlapping wipe effect
    const uint8_t start2 = (duration1 / 2) - (duration1 / 4);

    if ((beat >= start1) && (beat < (start1 + duration1))) {
        uint8_t progress = beat - start1;
        uint8_t wave = triwave8(map(progress, 0, duration1 - 1, 0, 255));
        brightness1 = ease8InOutCubic(wave);
    }
    if ((beat >= start2) && (beat < (start2 + duration2))) {
        uint8_t progress = beat - start2;
        uint8_t wave = triwave8(map(progress, 0, duration2 - 1, 0, 255));
        brightness2 = ease8InOutCubic(wave);
    }
  };

  // --- Calculate Brightness for Both Panels ---
  calculatePanelBrightness(back_beat, LED1_DURATION, LED2_DURATION, back_brightness1, back_brightness2);
  calculatePanelBrightness(front_beat, LED1_DURATION, LED2_DURATION, front_brightness1, front_brightness2);

  // --- Apply final values ---
  leds_inner_back[0] = back_color;
  leds_inner_back[0].nscale8(scale8(back_brightness1, BRIGHTNESS_INNER_BACK));
  leds_inner_back[1] = back_color;
  leds_inner_back[1].nscale8(scale8(back_brightness2, BRIGHTNESS_INNER_BACK));

  leds_inner_front[0] = front_color;
  leds_inner_front[0].nscale8(scale8(front_brightness1, BRIGHTNESS_INNER_FRONT));
  leds_inner_front[1] = front_color;
  leds_inner_front[1].nscale8(scale8(front_brightness2, BRIGHTNESS_INNER_FRONT));
}
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
void loop() {
  button_1.update();
  button_2.update();

  if ( button_1.fell() ) {
    outerPatternAdvance();
    innerPatternAdvance();
    FastLED.clear(); 
  }

  if ( button_2.fell() ) {
    patternBrightnessAdvance(); 
    FastLED.clear();
  }

  outerPatternList[outerCurrentPattern]();
  innerPatternList[innerCurrentPattern]();

  FastLED.show();  
  FastLED.delay(1000/ANIMATION_FPS); 
}

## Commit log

2025-07-15 Mapping brightness to button2 and saving the state to the EEPROM
2025-07-15 Trotek Laser Print Ready Files
2025-07-16 update laser cut files
